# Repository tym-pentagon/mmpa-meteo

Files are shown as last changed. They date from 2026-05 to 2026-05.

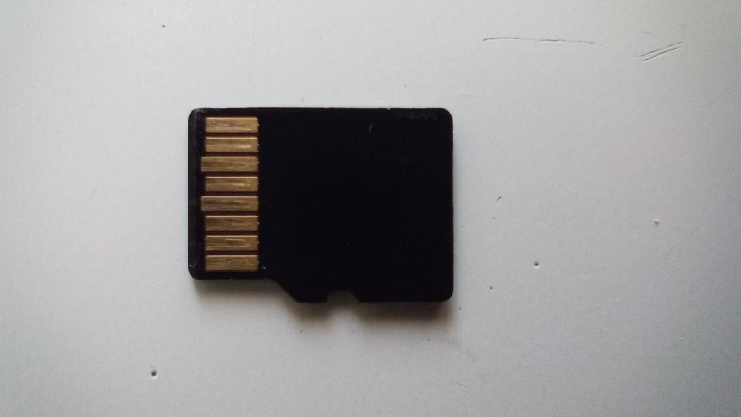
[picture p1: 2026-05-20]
Kod/Pomocne-skripty/obrazky/zdrojove-obrazky/sd_karta/sd_karta_fotka.jpeg

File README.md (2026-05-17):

# MMPa meteo
**MMPa meteo** je víceúčelová meteostanice určená pro analýzu atmosféry, magnetického pole Země a dalších jevů. 
Jedná se o projekt [týmu Pentagon](https://github.com/tym-pentagon). 

> [!TIP]
> Přečtěte si naši [dokumentaci](/Informace/README.md)!

> [!NOTE]
> #### Zdroje
> - [Knihovna pro ovládání ILI9486 LCD](https://github.com/RobertoBenjami/stm32_graphics_display_drivers)
> - [Knihovna pro ovládání SSD1306 OLED](https://github.com/afiskon/stm32-ssd1306)
> - [Čtení dat z BME280 přes I²C](https://controllerstech.com/interface-bme280-with-stm32/) - tutoriál
> - [BME280 datasheet](https://www.bosch-sensortec.com/media/boschsensortec/downloads/datasheets/bst-bme280-ds002.pdf)
> - [LoRa datasheet](https://www.mouser.com/pdfDocs/DS_LLCC68_V10-2.pdf)
> - [STM32 SD Card Interface via SPI and FatFS Tutorial (No RTOS)](https://www.youtube.com/watch?v=PBIm8BCnbyQ) - video tutoriál
> - Dimitar Toshkov Zhekov - Terminus Font
> - [Deepseek](https://chat.deepseek.com/) - generování programu pro export fontů
> - [ChatGPT](https://chatgpt.com/) & [GitHub Copilot modely](https://github.com/copilot) (studentská licence) - debugování

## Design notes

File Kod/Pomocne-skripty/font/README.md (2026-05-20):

# Font
Tato složka obsahuje skripty pro **vytváření a použití českého bitmapového fontu** v STM32CubeIDE. 

## [bdf-converter.py](./bdf-converter.py)
Konvertuje libovolný font ve formátu `.bdf` na soubor `.c`, který lze použít v STM32CubeIDE. 

### Použití
```bash
python3 bdf-converter.py input.bdf [output.c] [font_name]
```

### Zdroje
 - [DeepSeek](https://chat.deepseek.com/) - Generování kódu
 - Chyby v kódu opraveny týmem Pentagon

# Použití diakritiky
Vzhledem k tomu, že **STM32CubeIDE nepodporuje enkódování ISO-8859-2**, je pro zobrazení diakritiky a speciálních znaků potřeba text **převést do hexadecimálního formátu**. To obstarává skript [text-to-array.py](./text-to-array.py) (viz níže). 

## [text-to-array.py](./text-to-array.py)
Konvertuje **text na C array** s hexadecimálními hodnotami představujícími znaky ve formátu ISO-8859-2. 

### Použití
```bash
python3 text-to-array.py "your text here" [array_name]
```

### Zdroje
 - [DeepSeek](https://chat.deepseek.com/) - Generování kódu

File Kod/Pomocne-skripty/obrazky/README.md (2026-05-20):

# Obrázky
Tato složka obsahuje skripty pro **konvertování PNG obrázků na C skripty pro použití** v STM32CubeIDE. 

## [png-converter.py](./png-converter.py)
Konvertuje libovolný obrázek ve formátu `.png` na soubor `.c`, který lze použít v STM32CubeIDE. 

### Použití
```bash
python3 png-converter.py input.png image_name output.c
```

### Zdroje
 - [DeepSeek](https://chat.deepseek.com/) - Generování kódu
 - Kód byl částečně upraven týmem Pentagon

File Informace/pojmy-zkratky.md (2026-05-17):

## Pojmy a zkratky
Dokumentace k `MMPa meteo` využívá několik technických pojmů, které je třeba znát. Následující obsah je sestaven pro nováčky, kteří se projektu snaží porozumět.

| Zkratka | Pojem | Překlad | Definice
|-|-|-|-
|ADC|Analog-Digital converter|Analogově-digitální převaděč|Převaděč napětí na logické signály.
|DAC|Digital-Analog converter|Digitálně-analogový převaděč|Zdroj napětí nastavitelný logickými signály.
|DMA|Direct Memory Access|Přímý přístup do paměti|Funkcionalita umožňující periferii psát přímo do paměti MCU.
|MCU|MicroController unit|Mikrokontrolérová jednotka, mikrokontrolér|Jednotka, na které běží kód, matematické operace apod.
| |Peripheral|Periferie|Rozšíření funkčnosti a možností MCU.
|TIM|Timer|Časovač|Periferie určená k počtu a odpočtu.

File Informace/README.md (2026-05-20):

> [!WARNING]
> Tato dokumentace zahrnuje obecný stav projektu, nikoliv jeho vnitřní tok. Namísto vysvětlování je pro tento účel dočasně postavena prezentace [Mikrokontroléry letí 2026](about:blank).

> [!IMPORTANT]
> ### Stanice `MMPa meteo` se momentálně skládá ze dvou desek.
> **Deska vnější** je vybavena sensory, ze kterých po intervalech čte data a technologií [LoRa](/Informace/README.md#komunikace) je posílá desce vnitřní.  
> **Deska vnitřní** data přijímá z desky vnější, ukazuje je uživateli a zapisuje do SD karty.

> [!TIP]
> Projekt je budován tak, aby naplnil [základní kompetenční ustanovení](Informace/zakladni-kompetecni-listina.md).  
> Projekt při operaci musí naplňovat stanovení **MVP** (**M**inimum **V**iable **P**roduct), označeno ⁕.

## Složení stanice
`[`Ozávorkované`]` body čekají na implementaci.  
```mermaid
ishikawa-beta
    MMPa assembly
    Senzory
        [Akustický anemometr]
          rychlost větru
        BME280
          teplota
          relativní vlhkost
          tlak
        [osvětlení]
        [akcelerace (zemětřesení)]
    Komunikace
        Wireless
          LoRa
          [Bluetooth]
          [2.4 GHz Wi-Fi]
          [5 GHz Wi-Fi]
        Wired
          [RS-422]
          [RS-485]
    User
        INPUT
            Rotační enkodér
        OUTPUT
            Displej
            SD karta
    +
      GPS
```
> [!TIP]
> Pokud jsi **nováček**, doporučujeme přečíst [Pojmy & zkratky](/Informace/pojmy-zkratky.md).
### Senzorová soustava
| Veličina || Senzor | Vstup | Výstup |
|:---:|:-:|:---:|:---:|:---:|
||||||
| Vítr - rychlost ||  Akustický anemometr dvouosý  | 2x zvuková křivka | $\text{ms}^{-1}$ | 
| Vítr - směr ||  Akustický anemometr dvouosý  | 2x zvuková křivka | $\degree$ |
| Teplota |⁕| BME280 | Binární data | $\textdegree C$ |
| Vlhkost |⁕| BME280 | Binární data | % |
| Tlak |⁕| BME280 | Binární data | $\text{MPa}$ |
| Čas |⁕| GPS | LoRa | $\text{ms}$ |
| Zemětřesení ||  Akcelerometr LIS3DH  | *TBD* |  st. zemětřesení  |
| Světlo || 2 diody BPW34S | Analog. | oblačnost |
#### BME280
BME je modul měříci teplotu, vlhkost vzduchu a tlak okolí. K desce je připojen přes **SPI**.
##### Pocitová teplota
K teplotě ještě řadíme **pocitovou teplotu**, kterou získáme ze vzorce, přičemž potřebujeme hodnotu:
 - reálné teploty
 - rychlosti větru
 - vlhkosti vzduchu

Možné vzorce pro použití:
- [AAT](https://en.wikipedia.org/wiki/Apparent_temperature)  (australský systém, navržen pro celoroční výpočty)
- [Wind Chill](https://en.wikipedia.org/wiki/Wind_chill)  (kanadský standard, navržen pro nižší teploty cca do 10°C)
- [Heat Index](https://en.wikipedia.org/wiki/Heat_index) (pro teplejší počasí nad 27°C s vlhkostí nad 40%)

>[!NOTE]
>Vzorce jsou hlavně určené pro měření ve **stínu**.  
>Lze použít více vzorců pro různá období.  
  
#### Osvětlení
Pro detekci osvětlení se používají dvě fotodiody [BPW34S](https://look.ams-osram.com/m/1f206a499ac1f0b2/original/BPW-34-S.pdf). Jejich výstupy budou zavedeny do MCU jako kanály nízkofrekvenčního ADC
Každá fotodioda je sériově připojena k resistoru s odporem $R$ a k němu paralelně operačnímu zesilovači.
- **Denní osvětlení** vrací dioda `D800`, na kterou navazuje se zesilovačem odpor $R = 10 \text{ k}\Omega$, dokážeme s ní tedy zachycovat makroskopické měřítko s přesností pro denní svit dostatečnou.
- **Noční osvětlení** (světelný smog) vrací dioda `D801`, kde $R = 1 \text{ M}\Omega$, lze s ní receptovat malé rozmezí s velmi velkou přesností.
Spoluprácí obou diod dokážeme optimálně pokrýt celé reálné světelné rozmezí.

Viz. [schéma](/Schema/schema.pdf).

### Komunikace

| Typ komunikace || Rychlost | Dosah  |
|---|-|---|---|
| [LoRa](https://cs.wikipedia.org/wiki/LoRa)|⁕| 11 $\text{bps}$ - 203 $\text{kbps}$ | 4.8 $\text{km}$ |
| 2.4 $\text{GHz}$ Wi-Fi  || 450 $\text{Mbps}$ - 600 $\text{Mbps}$ | 36 $\text{m}$ |
| 5 $\text{GHz}$ Wi-Fi || 1.3 $\text{Gbps}$ | 12 $\text{m}$ |
| [Bluetooth](https://cs.wikipedia.org/wiki/Bluetooth)|| dle verze (max 24 $\text{MBps}$)| dle verze (max 100 $\text{m}$)|
> [!NOTE]
> Jde pouze o přibližné hodnoty, skutečný dosah a rychlost budou omezeny rychlostí mikrokontroléru, rušením signálu a typem prostředí. 

#### LoRa: Předávané proměnné
| Index | Typ proměnné |  Název proměnné  |
|---|---|---|
| 0-1 | int16_t | cas.rok |
| 2 | int8_t | cas.mesic |
| 3 | int8_t | cas.den |
| 4 | int8_t | cas.hodiny |
| 5 | int8_t | cas.minuty |
| 6 | int8_t | cas.sekundy |
| 7-10	| int32_t | teplota |
| 11-14	| uint32_t | vlhkost |
| 15-18 | uint32_t | tlak |
| 19-60 | | |
| 61 | uint8_t | crc |

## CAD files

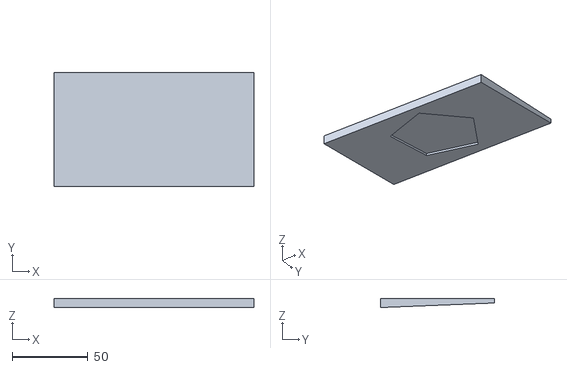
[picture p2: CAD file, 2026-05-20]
Modely/Monitor unit roof.stl
132.0 x 75.0 x 6.00

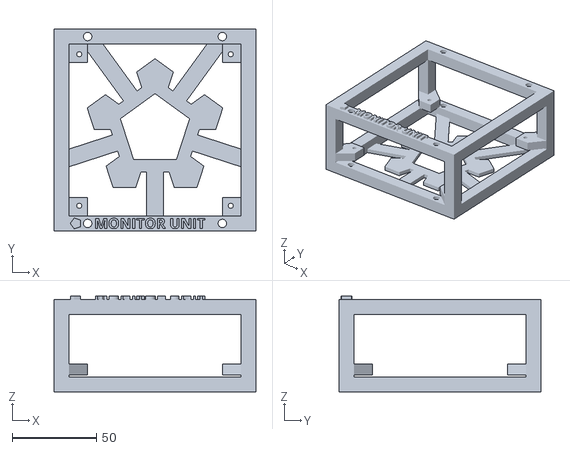
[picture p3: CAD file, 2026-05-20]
Modely/Monitor unit PCB holder.stl
120.0 x 120.0 x 57.0

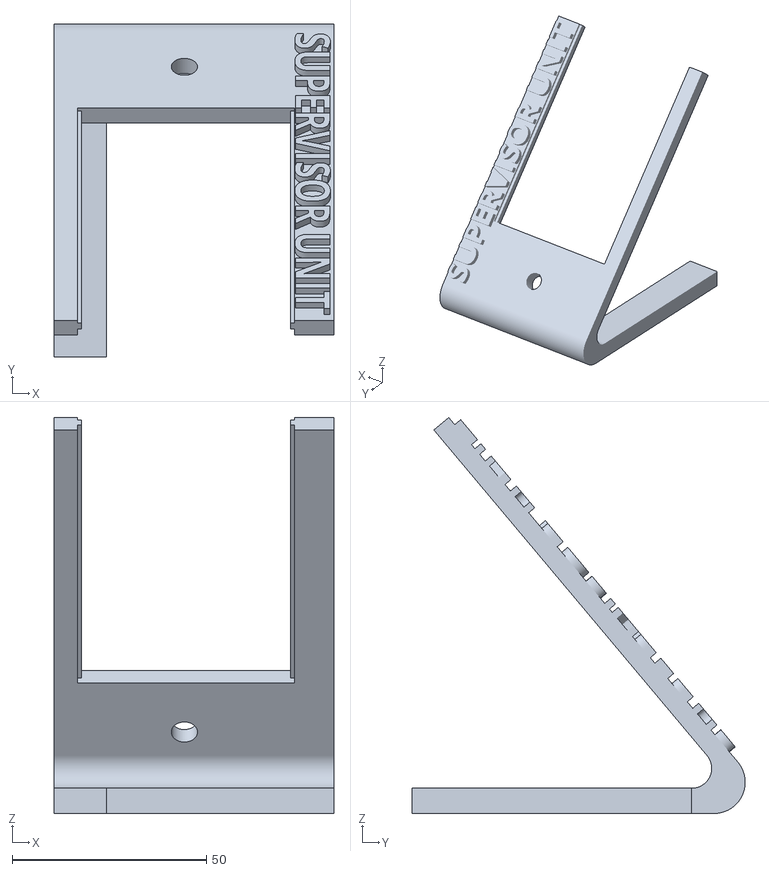
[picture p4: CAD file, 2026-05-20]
Modely/Supervisor unit display holder.stl
72.0 x 85.8 x 101.9

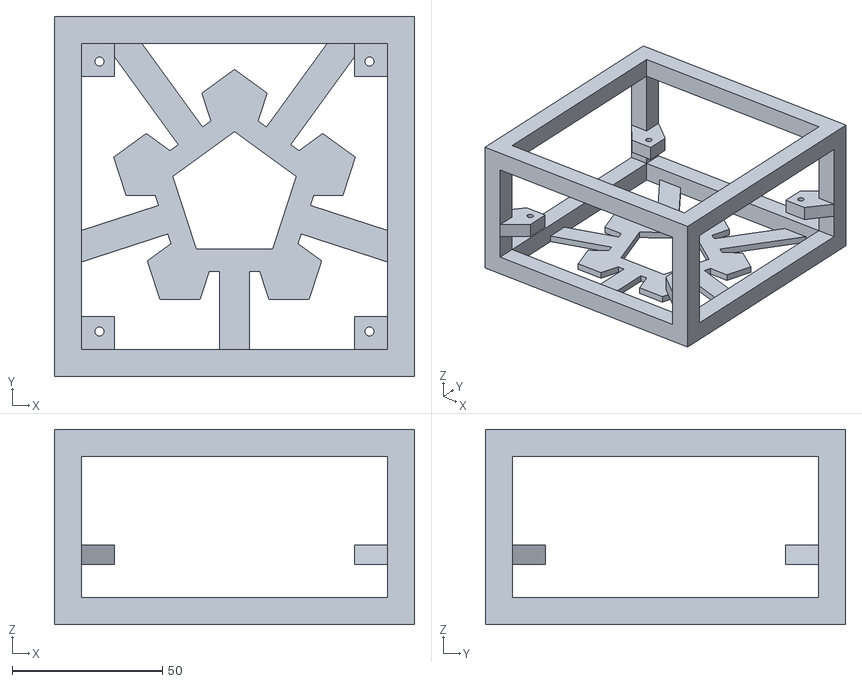
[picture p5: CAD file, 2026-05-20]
Modely/Supervisor unit PCB holder.stl
120.0 x 120.0 x 65.0

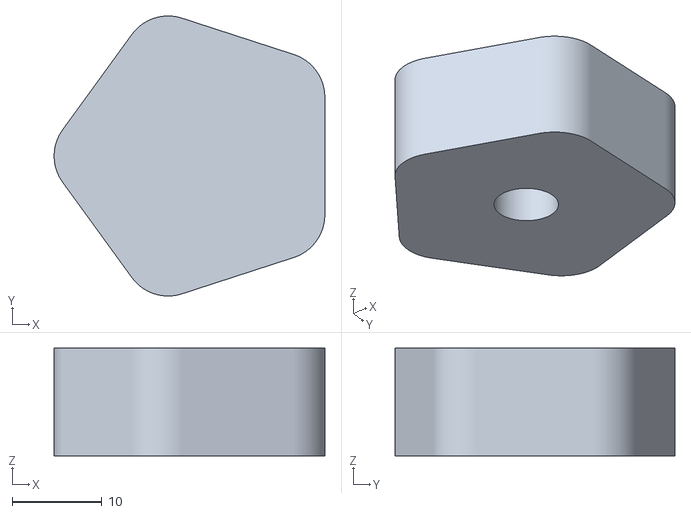
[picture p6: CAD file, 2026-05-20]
Modely/Supervisor unit rotary encoder knob.stl
30.1 x 31.2 x 12.0

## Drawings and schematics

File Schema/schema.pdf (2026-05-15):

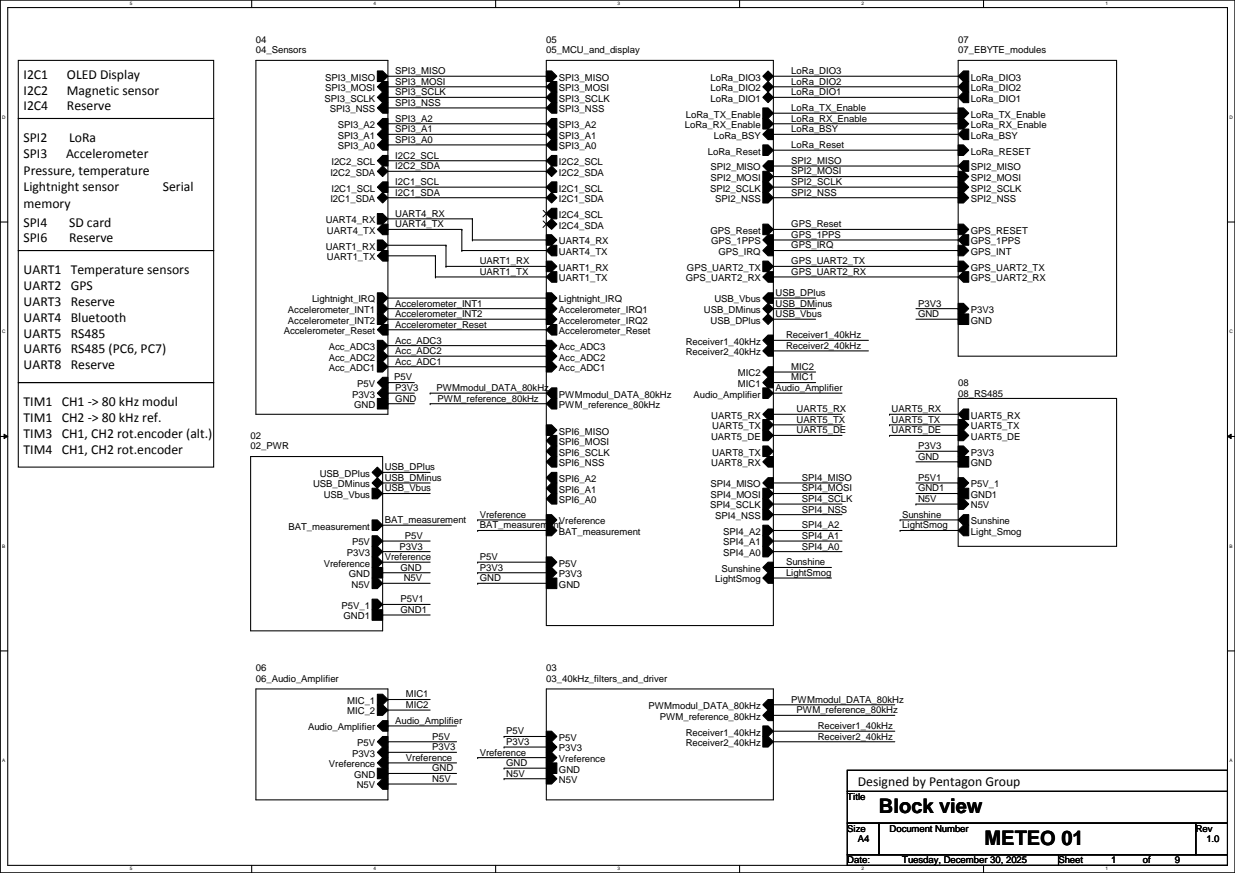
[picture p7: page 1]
Vreference; GND; GND N5V; Audio_Amplifier; GND1; USB_Vbus; USB_DPlus USB_DMinus; P3V3 GND; MIC2; MIC1; USB_DMinus; USB_DPlus; PWMmodul_DATA_80kHz PWM_reference_80kHz; UART5_RX UART5_TX UART5_DE; LoRa_DIO3; LoRa_RX_Enable; SPI2_MISO SPI2_MOSI SPI2_SCLK; GPS_1PPS; GPS_UART2_RX; GPS_IRQ GPS_UART2_TX; Receiver1_40kHz Receiver2_40kHz; SPI3_MISO; SPI3_A2; I2C2_SCL I2C2_SDA I2C1_SCL; UART4_TX; UART1_RX UART1_TX; Accelerometer_INT1 Accelerometer_INT2 Accelerometer_Reset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

SPI3_MOSI | LoRa_DIO2
SPI3_SCLK | LoRa_DIO1
SPI3_NSS | LoRa_TX_Enable

SPI3_A1 | LoRa_BSY
SPI3_A0 | LoRa_Reset

I2C1_SDA | SPI2_NSS

UART4_RX | GPS_Reset

TIM1 CH1 -> 80 kHz modul
TIM1 CH2 -> 80 kHz ref.
TIM3 CH1, CH2 rot.encoder (alt.)
TIM4 CH1, CH2 rot.encoder

Designed by Pentagon Group
Title
Block view

## Power Supply ±5 V

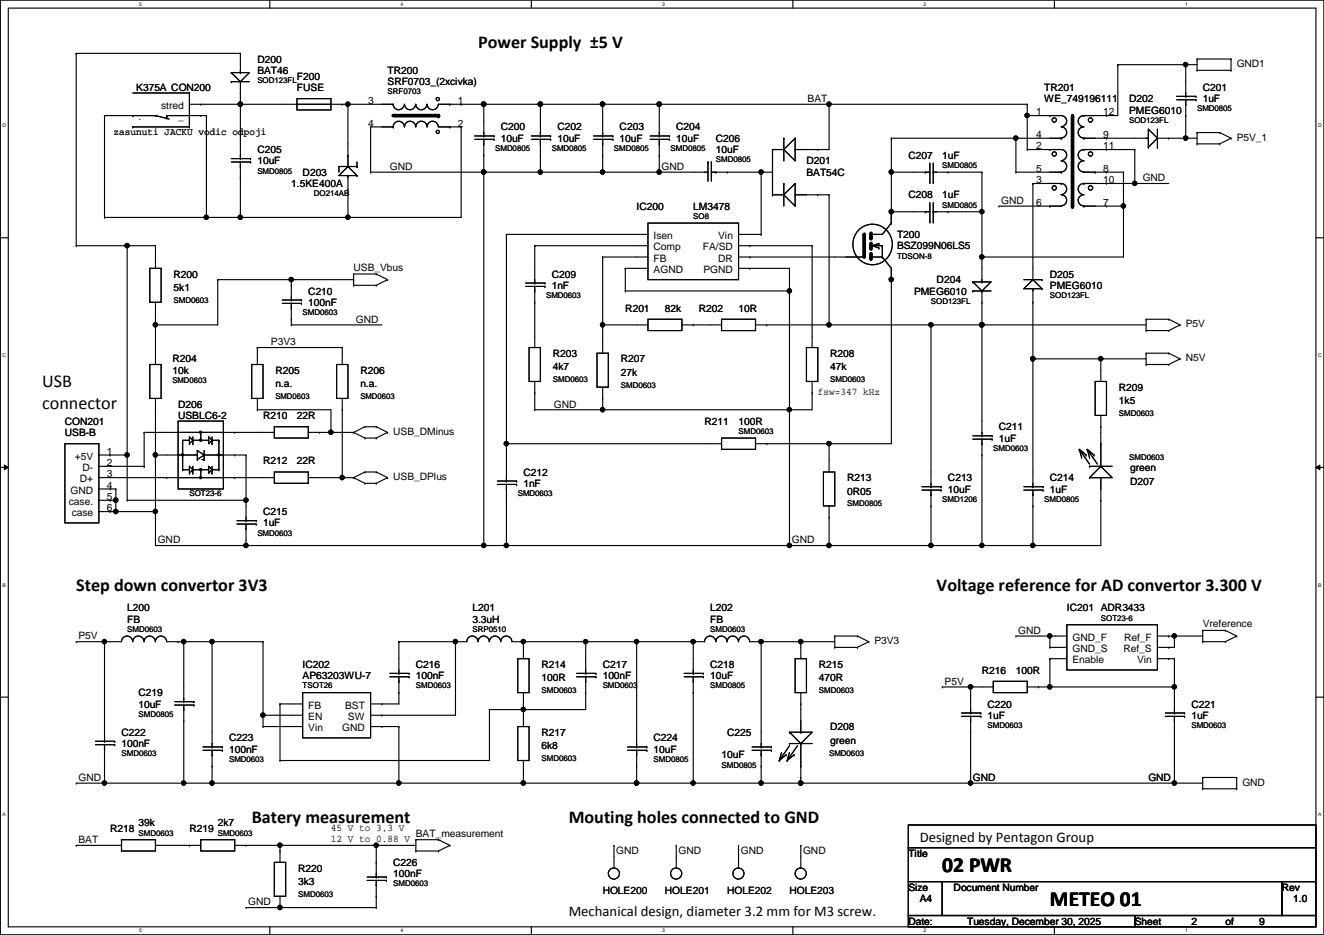
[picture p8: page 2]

zasunuti JACKU vodic odpoji

Mouting holes connected to GND

Designed by Pentagon Group
Title
02 PWR

HOLE200
Mechanical design, diameter 3.2 mm for M3 screw.

## Ultrasound receiver 1 filter (40 kHz)

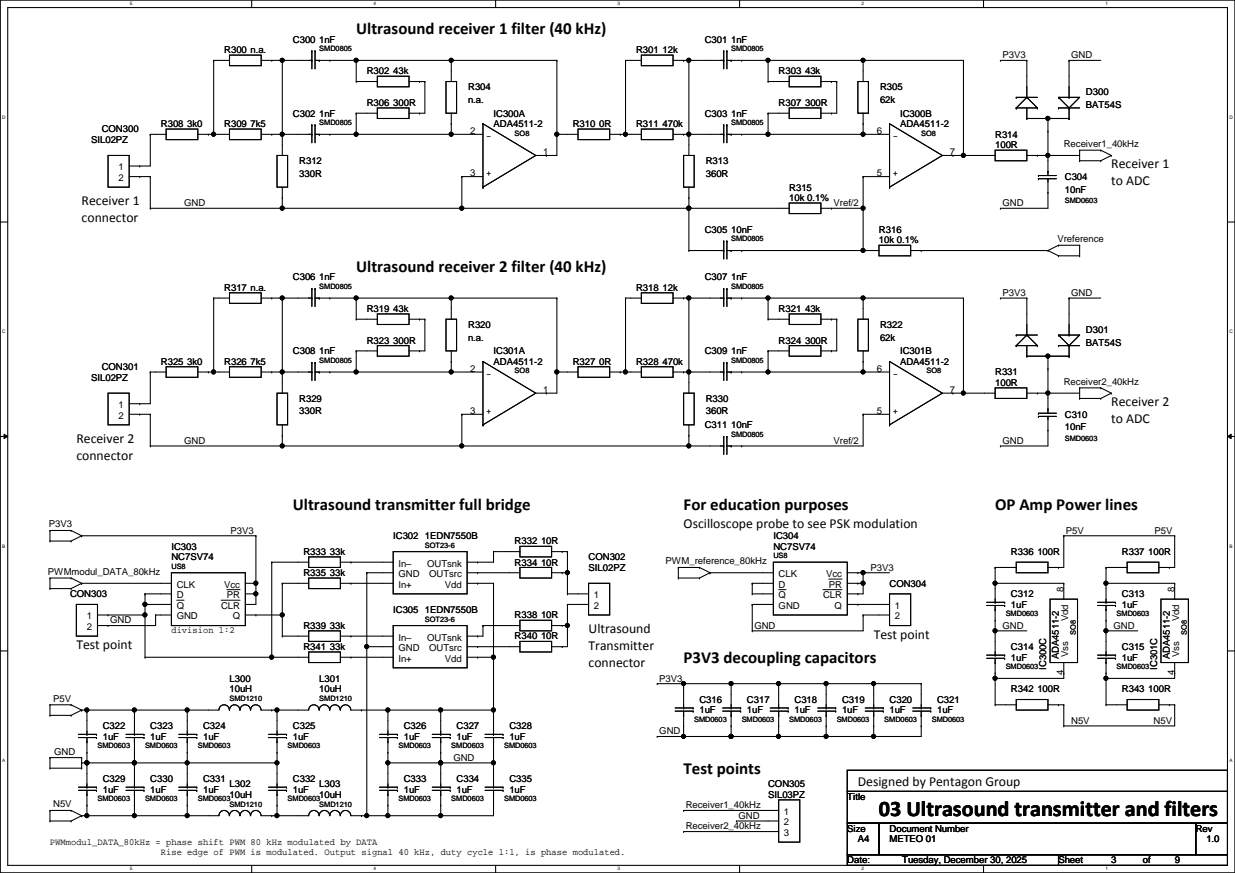
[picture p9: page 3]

Ultrasound receiver 2 filter (40 kHz)

For education purposes
Oscilloscope probe to see PSK modulation

Designed by Pentagon Group
Title
03 Ultrasound transmitter and filters

PWMmodul_DATA_80kHz = phase shift PWM 80 kHz modulated by DATA

Rise edge of PWM is modulated. Output signal 40 kHz, duty cycle 1:1, is phase modulated.

## Bluetooth

## Accelerometer

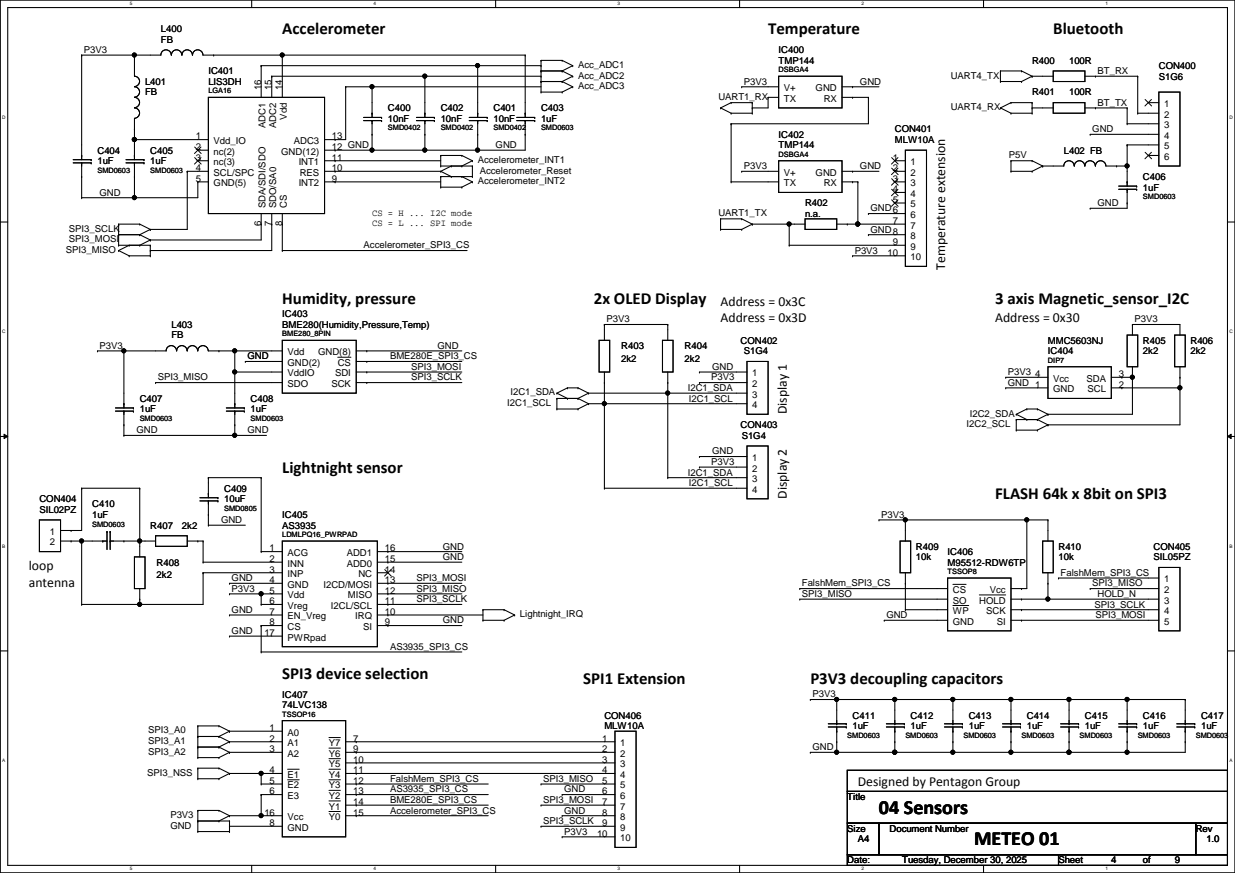
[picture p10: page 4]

9 IRQ 10 I2CL/SCL 11 MISO 12 I2CD/MOSI 13 NC 14 ADD0 15 ADD1 16

P3V3 decoupling capacitors SPI3 device selection

## SWD connector

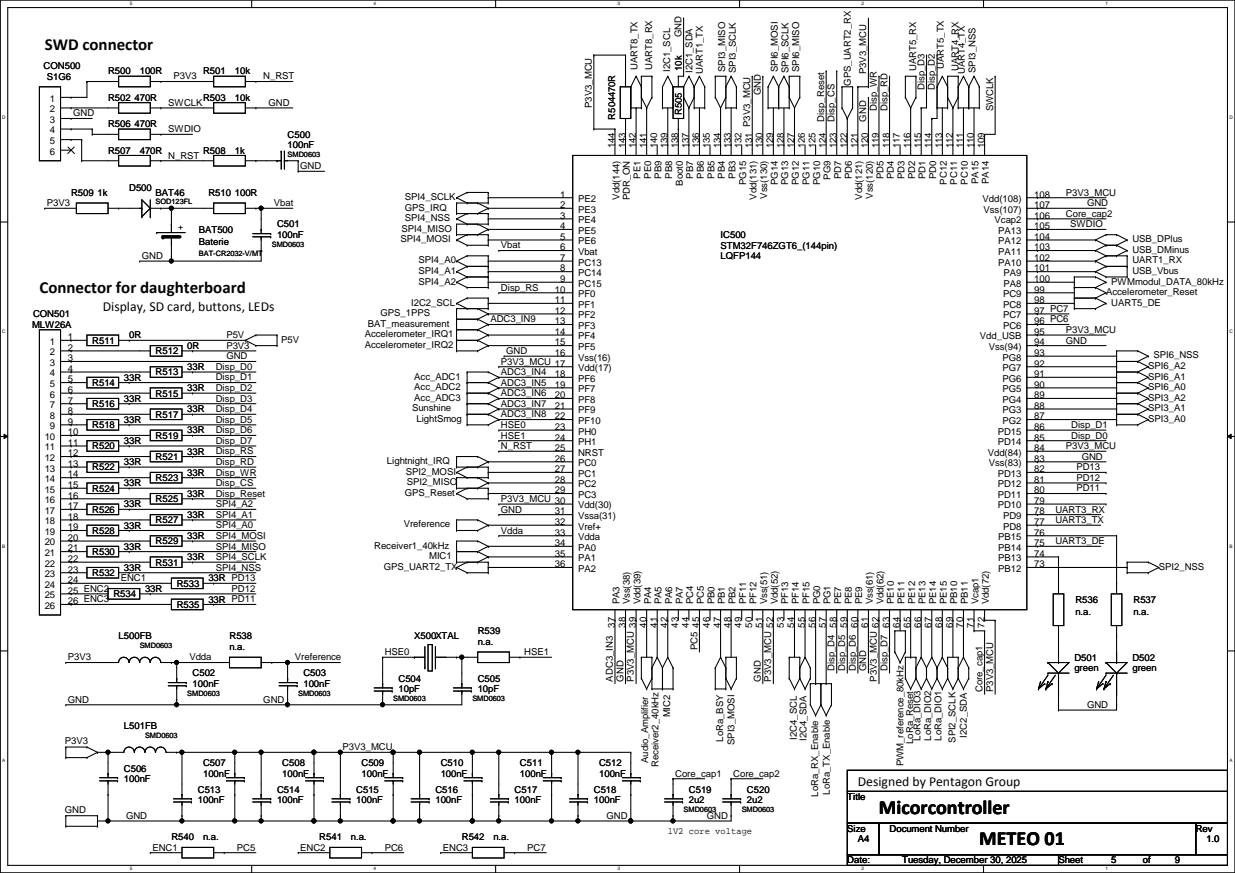
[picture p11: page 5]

Display, SD card, buttons, LEDs

Designed by Pentagon Group
Title
Micorcontroller

L600 FB | Audio Amplifier

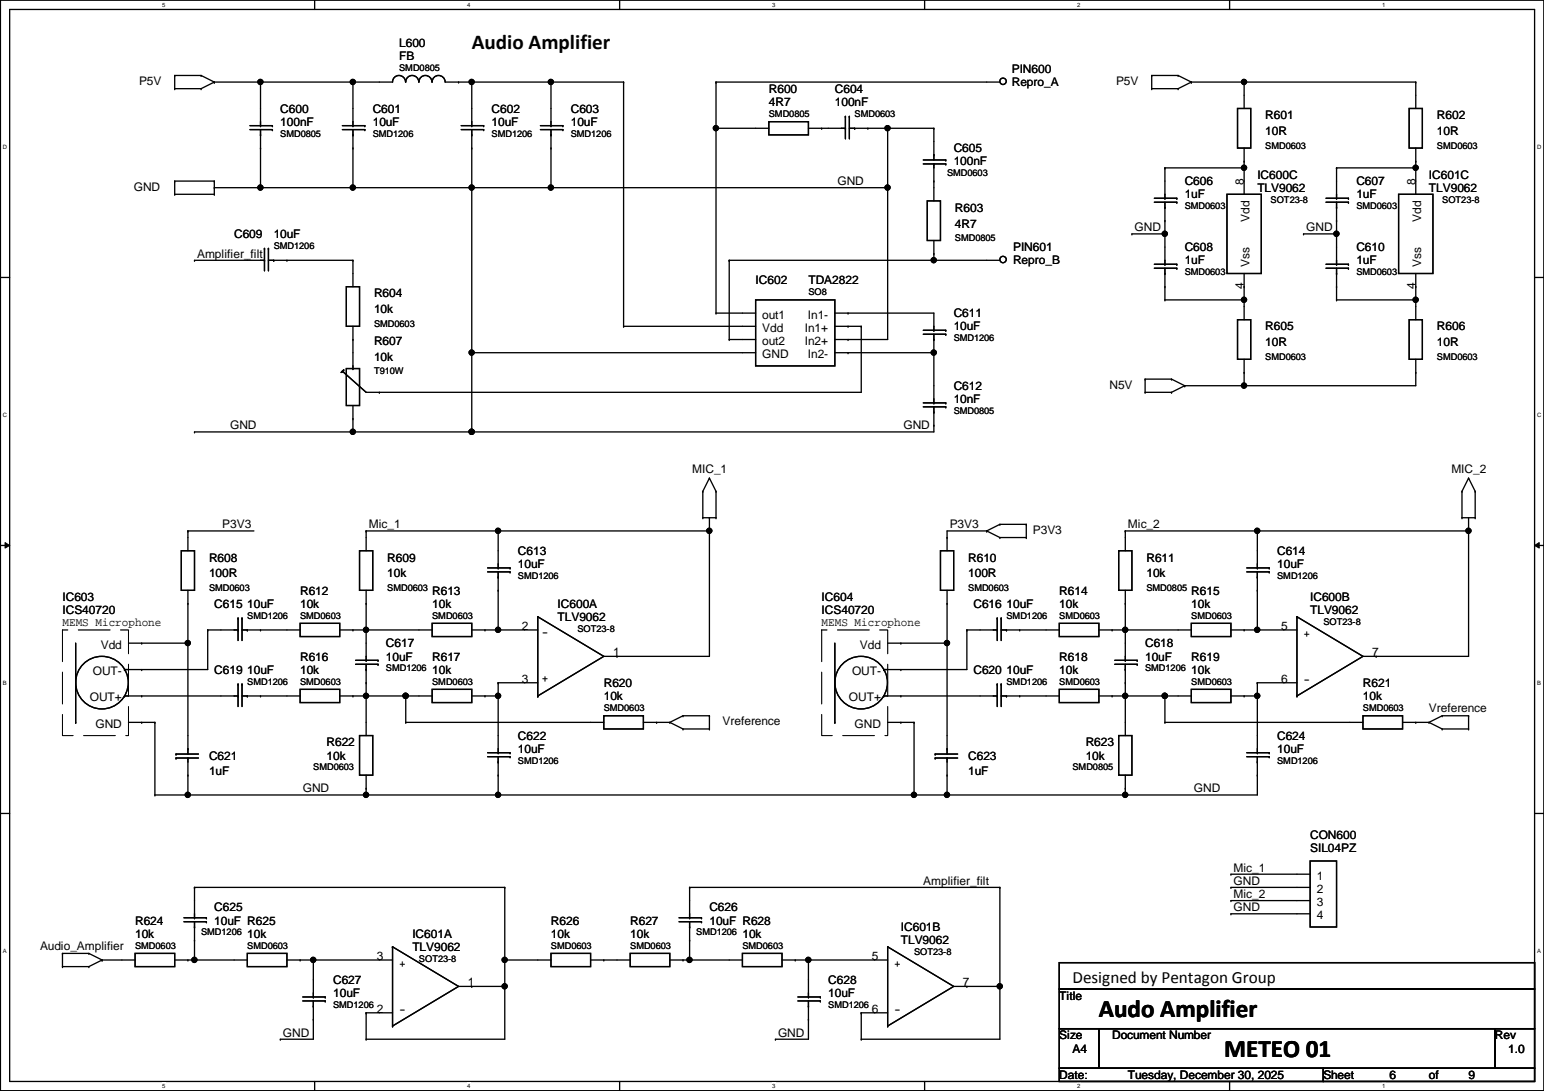
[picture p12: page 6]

SMD0805 | SMD0603

Designed by Pentagon Group
Title
Audo Amplifier

## GPS

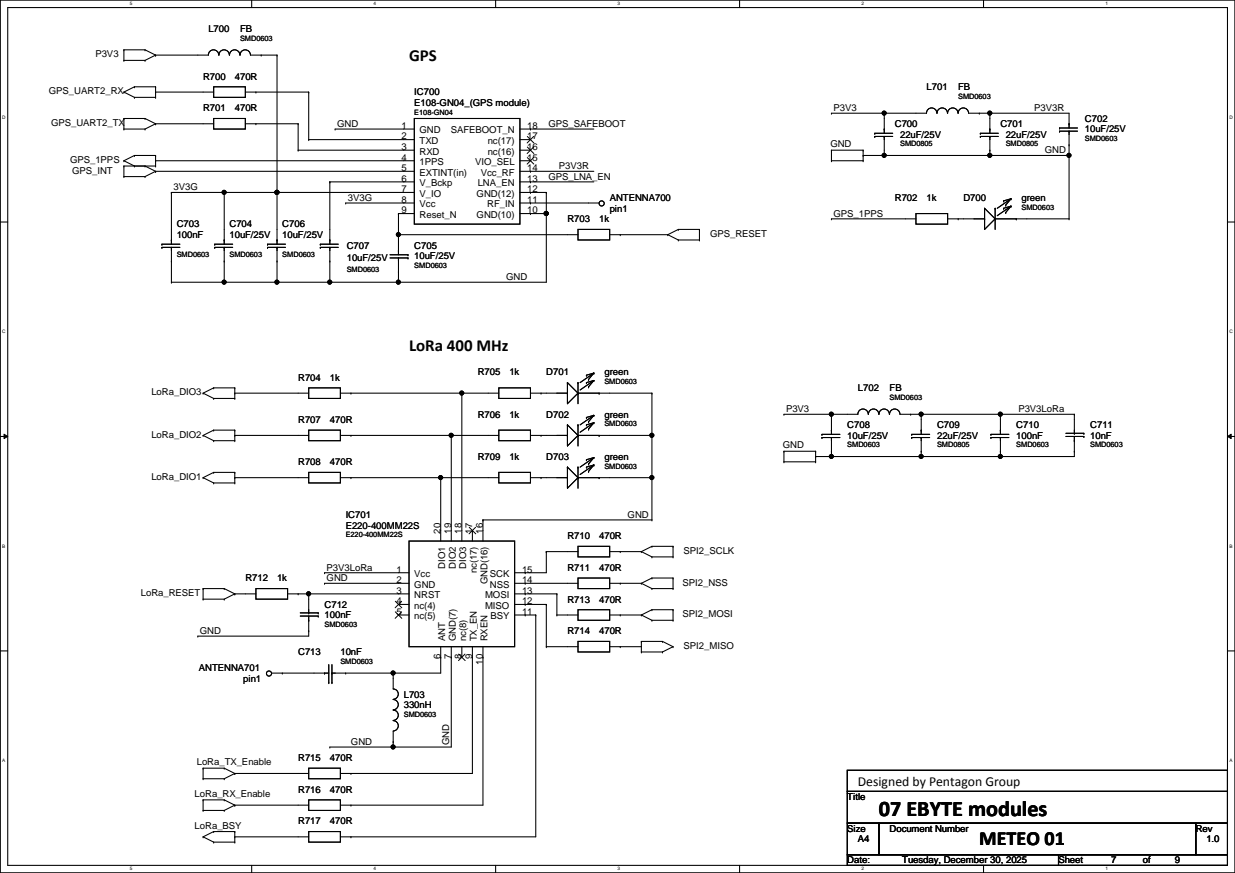
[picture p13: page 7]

DIO3
BSY 11 MISO 12 MOSI 13 NSS 14 SCK 15

Designed by Pentagon Group
Title
07 EBYTE modules

## RS485 Interface

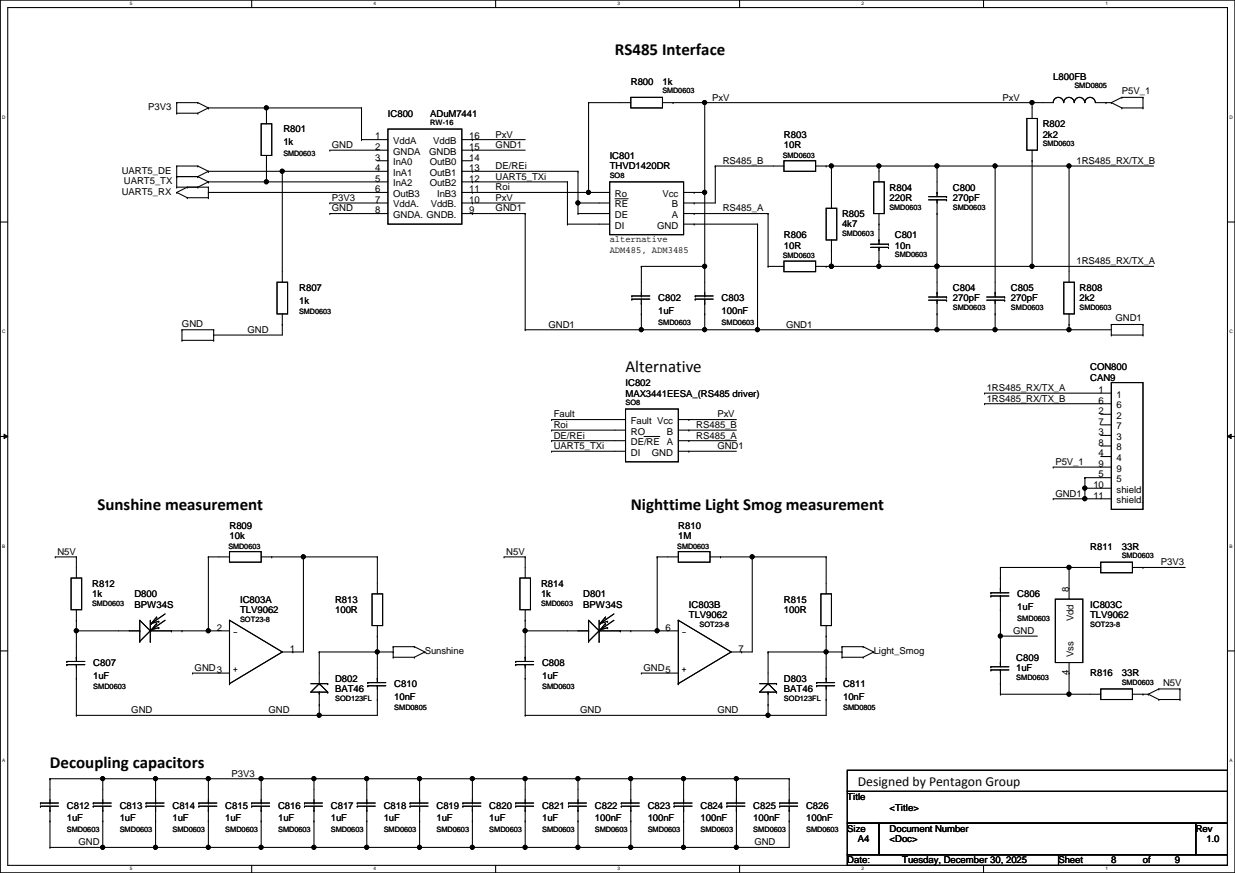
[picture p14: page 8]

Designed by Pentagon Group
Title

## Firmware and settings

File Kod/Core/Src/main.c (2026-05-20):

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
/* Includes ------------------------------------------------------------------*/
#include "main.h"
#include "adc.h"
#include "fatfs.h"
#include "i2c.h"
#include "spi.h"
#include "tim.h"
#include "usart.h"
#include "gpio.h"

/* USER CODE BEGIN Includes */
#include "stm32_adafruit_lcd.h"
#include "ssd1306.h"
#include "stdio.h"
#include "string.h"
#include "stdarg.h" // For va_list var arg functions
#include "stdbool.h"
#include "sd.h"

/* Komunikace */
#include "lora.h"

/* Senzory */
#include "bme280.h"
#include "gps.h"

/* Stránky */
#include "hlavni_menu.h"
#include "atmosfera.h"
/* USER CODE END Includes */


/* USER CODE BEGIN PV */
bool pripojeno = 1;
uint16_t ping = 9999;

Cas predchozi_cas = {2026, 4, 15, 14, 39, 2}; // Čas při předchozí aktualizace hodin
extern Cas cas;

uint16_t predchozi_pozice_vyberu = 0;
uint16_t pozice_vyberu = 0;
uint16_t max_pozice_vyberu = 10;

int32_t teplota;
uint32_t vlhkost, tlak;

int32_t teplota_venku;
uint32_t vlhkost_venku, tlak_venku;

bool stisknuto = 0; // Zda bylo stisknuto tlačítko na rotačním enkodéru

extern bool sd_karta_pripojena;
extern uint32_t kapacita_sd_karty;
extern uint32_t zaplneni_sd_karty;

uint8_t strana = 0;

const char nazvy_mesicu[12][10] = {
	{0x6C, 0x65, 0x64, 0x6E, 0x61, 0x00},							// "ledna"
	{0xFA, 0x6E, 0x6F, 0x72, 0x61, 0x00},							// "února"
	{0x62, 0xF8, 0x65, 0x7A, 0x6E, 0x61, 0x00},						// "března"
	{0x64, 0x75, 0x62, 0x6E, 0x61, 0x00},							// "dubna"
	{0x6B, 0x76, 0xEC, 0x74, 0x6E, 0x61, 0x00},						// "května"
	{0xE8, 0x65, 0x72, 0x76, 0x6E, 0x61, 0x00},						// "června"
	{0xE8, 0x65, 0x72, 0x76, 0x65, 0x6E, 0x63, 0x65, 0x00},			// "července"
	{0x73, 0x72, 0x70, 0x6E, 0x61, 0x00},							// "srpna"
	{0x7A, 0xE1, 0xF8, 0xED, 0x00},									// "září"
	{0xF8, 0xED, 0x6A, 0x6E, 0x61, 0x00},							// "října"
	{0x6C, 0x69, 0x73, 0x74, 0x6F, 0x70, 0x61, 0x64, 0x75, 0x00},	// "listopadu"
	{0x70, 0x72, 0x6F, 0x73, 0x69, 0x6E, 0x63, 0x65, 0x00}			// "prosince"
};
/*
 * 0 - hlavní menu
 */

char debug[500];

extern bool can_send_data; // Zda LoRa může posílat data

uint8_t lora_data[DATA_LEN]; // Data pro odeslání

extern bool jednotka_ma_gps;
extern bool jednotka_ziskala_cas_z_gps;

bool mereni = false; // Zda se MCU má ptát senzorů na aktuální hodnoty
bool je_cas_zapsat_log = false;
// Měří se každou sekundu
// Omezení je z důvodu přehřívání senzorů
/* USER CODE END PV */

void SystemClock_Config(void);
static void MPU_Config(void);
/* USER CODE BEGIN PFP */
void aktualizujCas(Cas *cas);
void aktualizujPoziciVyberu(void);
void tlacitkoStisknuto(void);
void pridatChecksum(uint8_t data[], size_t data_len);
void pripravitDataProOdeslani(void);
bool zkontrolovatChecksum(uint8_t data[], size_t data_len);
/* USER CODE END PFP */

/* USER CODE BEGIN 0 */
void aktualizujCas(Cas *cas) {
	/* Tato funkce se spustí každou sekundu, vždy aktualizuje proměnnou cas */
	cas->sekundy ++;

	if (cas->sekundy >= 60) {
		cas->sekundy = 0;
		cas->minuty ++;

		if (cas->minuty >= 60) {
			cas->minuty = 0;
			cas->hodiny ++;

			if (cas->hodiny >= 24) {
				cas->hodiny = 0;
				cas->den ++;

				if (
					(cas->den >= 31 && (		// Měsíce se 31 dny
						cas->mesic == 1 ||		// Leden
						cas->mesic == 3 ||		// Březen
						cas->mesic == 5 || 		// Květen
						cas->mesic == 7 ||		// Červenec
						cas->mesic == 8 ||		// Srpen
						cas->mesic == 10 ||		// Říjen
						cas->mesic == 12		// Prosinec
					)) ||
					(cas->den > 30 && (			// Měsíce se 30 dny
						cas->mesic == 4 ||		// Duben
						cas->mesic == 6 ||		// Červen
						cas->mesic == 9 || 		// Září
						cas->mesic == 11		// Listopad
					)) ||
					(cas->den >= 29 && cas->rok % 4 == 0 && cas->rok % 100 != 0 && cas->rok % 400 == 0) ||	// Únor v přestupném roku
					cas->den >= 28																			// Únor v nepřestupném roku
				) {
					cas->den = 0;
					cas->mesic ++;

					if (cas->mesic >= 13) {
						cas->mesic = 1;
						cas->rok ++;
					}
				}
			}
		}
	}
}

void aktualizujPoziciVyberu(void) {
	if (TIM3->CNT % 2 == 0 && TIM3->CNT != pozice_vyberu * 2) {
		predchozi_pozice_vyberu = pozice_vyberu;

		if (TIM3->CNT > 65000) { // Underflow
			TIM3->CNT = (max_pozice_vyberu + 1) * 2 - ((65536 - TIM3->CNT) % ((max_pozice_vyberu + 1) * 2));
		}

		if (TIM3->CNT > max_pozice_vyberu * 2) {
			TIM3->CNT = TIM3->CNT % ((max_pozice_vyberu + 1) * 2);
		}

		pozice_vyberu = TIM3->CNT / 2;

		if (strana == 0) {
			aktualizujPoziciVyberuVHlavnimMenu(predchozi_pozice_vyberu, pozice_vyberu);
		}

		/* Vypíše na debug displej */
		char pozice_vyberu_buffer[6];
		snprintf(pozice_vyberu_buffer, 6, "%d", pozice_vyberu);

		ssd1306_SetCursor(122, 0);
		ssd1306_WriteString(pozice_vyberu_buffer, &Terminus12Bold, 1);
		ssd1306_UpdateScreen();
	}
}

void tlacitkoStisknuto(void) {
	ssd1306_SetCursor(122, 13);
	ssd1306_WriteString("1", &Terminus12Bold, 1);
	ssd1306_UpdateScreen(); // Vykreslí na OLED displej

	if (strana == 0) {
		if (pozice_vyberu == 0) {
			strana = 1;
			vykresliStrankuAtmosfera(&predchozi_pozice_vyberu, &pozice_vyberu, &max_pozice_vyberu);
		}
	}
	else if (strana == 1) {
		if (pozice_vyberu == 0) {
			strana = 0;
			vykresliHlavniMenu(pripojeno, ping, cas, &predchozi_pozice_vyberu, &pozice_vyberu, &max_pozice_vyberu);
		}
	}

	ssd1306_SetCursor(122, 13);
	ssd1306_WriteString("0", &Terminus12Bold, 1);
	ssd1306_UpdateScreen(); // Vykreslí na OLED displej
}

void pridatChecksum(uint8_t data[], size_t data_len) {
	uint8_t crc = 0;

	for (size_t i = 0; i < data_len - 1; i ++) {
		crc ^= data[i];
	}

	data[data_len - 1] = crc;
}

void pripravitDataProOdeslani() {
	memset(lora_data, 0, DATA_LEN); // Vynuluje data pro odeslání

	if (jednotka_ziskala_cas_z_gps) {
		lora_data[0] = (cas.rok >> 8) & 0xFF; // MSB
		lora_data[1] = cas.rok & 0xFF; // LSB

		lora_data[2] = cas.mesic;
		lora_data[3] = cas.den;

		lora_data[4] = cas.hodiny;
		lora_data[5] = cas.minuty;
		lora_data[6] = cas.sekundy;
	}

	lora_data[7] = (teplota >> 24) & 0xFF; // MSB
	lora_data[8]  = (teplota >> 16) & 0xFF;
	lora_data[9] = (teplota >> 8)  & 0xFF;
	lora_data[10] = teplota & 0xFF;         // LSB

	lora_data[11] = (vlhkost >> 24) & 0xFF; // MSB
	lora_data[12]  = (vlhkost >> 16) & 0xFF;
	lora_data[13] = (vlhkost >> 8)  & 0xFF;
	lora_data[14] = vlhkost & 0xFF;         // LSB

	lora_data[15] = (tlak >> 24) & 0xFF; // MSB
	lora_data[16]  = (tlak >> 16) & 0xFF;
	lora_data[17] = (tlak >> 8)  & 0xFF;
	lora_data[18] = tlak & 0xFF;         // LSB

	pridatChecksum(lora_data, DATA_LEN);

	LoRa_set_data(lora_data, sizeof(lora_data));
}

bool zkontrolovatChecksum(uint8_t data[], size_t data_len) {
	uint8_t crc = 0;

	for (size_t i = 0; i < data_len - 1; i ++) {
		crc ^= data[i];
	}

	if (data[data_len - 1] == crc) {
		return true; // Checksum sedí
	}
	else {
		return false; // Checksum nesedí
	}
}

void LoRa_Rx_callback(uint8_t data_received[], uint8_t len) {
	if (!zkontrolovatChecksum(data_received, len)) {
		// Checksum nesedí
		// TODO: Error handling
	}

	if (!jednotka_ma_gps && (data_received[0] != 0 || data_received[1] != 0 || data_received[2] != 0 || data_received[3] != 0 || data_received[4] != 0 || data_received[5] != 0 || data_received[6] != 0)) {
		cas.rok =
			((uint16_t)data_received[0] << 8) |
			((uint16_t)data_received[1]);

		cas.mesic = (uint8_t)data_received[2];
		cas.den = (uint8_t)data_received[3];

		cas.hodiny = (uint8_t)data_received[4];
		cas.minuty = (uint8_t)data_received[5];
		cas.sekundy = (uint8_t)data_received[6];
	}

	teplota_venku =
		(int32_t)(
			((uint32_t)data_received[7] << 24) |
			((uint32_t)data_received[8] << 16) |
			((uint32_t)data_received[9] << 8)  |
			((uint32_t)data_received[10])
		);

	vlhkost_venku =
		((uint32_t)data_received[11] << 24) |
		((uint32_t)data_received[12] << 16) |
		((uint32_t)data_received[13] << 8)  |
		((uint32_t)data_received[14]);

	tlak_venku =
		((uint32_t)data_received[15] << 24) |
		((uint32_t)data_received[16] << 16) |
		((uint32_t)data_received[17] << 8)  |
		((uint32_t)data_received[18]);
}
/* USER CODE END 0 */

/**
  * @brief  The application entry point.
  * @retval int
  */
int main(void)
{

  /* MPU Configuration--------------------------------------------------------*/
  MPU_Config();

  /* MCU Configuration--------------------------------------------------------*/

  /* Reset of all peripherals, Initializes the Flash interface and the Systick. */
  HAL_Init();

  /* USER CODE BEGIN Init */
  HAL_Delay(2000); // Počká, než se všechny periferie inicializují a jsou schopné komunikovat.
  /* USER CODE END Init */

  /* Configure the system clock */
  SystemClock_Config();

  /* Initialize all configured peripherals */
  MX_GPIO_Init();
  MX_ADC3_Init();
  MX_TIM3_Init();
  MX_I2C1_Init();
  MX_SPI4_Init();
  MX_FATFS_Init();
  MX_TIM13_Init();
  MX_TIM2_Init();
  MX_SPI3_Init();
  MX_SPI2_Init();
  MX_TIM11_Init();
  MX_USART2_UART_Init();
  /* USER CODE BEGIN 2 */
  LoRa_init();
  gps_init();

  HAL_ADC_Start(&hadc3);

  if (BSP_LCD_Init() != LCD_OK) {
  	Error_Handler(); // Inicializace LCD selhala
  	return 1;
  }

  ssd1306_Init(); // Inicializace OLED displeje

  /* Inicializace BME280 */
  if (BME280_Config(OSRS_16, OSRS_16, OSRS_16, MODE_NORMAL, T_SB_1000, IIR_16) != 0) {
	  Error_Handler();
  }

  /* Debug pozice výběru */
  char pozice_vyberu_text[] = {
	0x50, 0x6F, 0x7A, 0x69, 0x63, 0x65, 0x20, 0x76, 0xFD, 0x62, 0xEC, 0x72, 0x75, 0x3A, 0x00,  // "Pozice výběru:"
  };

  ssd1306_SetCursor(0, 0);
  ssd1306_WriteString(pozice_vyberu_text, &Terminus12Normal, 1);

  ssd1306_SetCursor(122, 0);
  ssd1306_WriteString("0", &Terminus12Bold, 1); // Počáteční pozice výběru je vždy 0

  /* Debug stisknuto */
  char stisknuto_text[] = {
    0x53, 0x74, 0x69, 0x73, 0x6B, 0x6E, 0x75, 0x74, 0x6F, 0x3A, 0x00,  // "Stisknuto:"
  };

  ssd1306_SetCursor(0, 13);
  ssd1306_WriteString(stisknuto_text, &Terminus12Normal, 1);

  ssd1306_SetCursor(122, 13);
  ssd1306_WriteString("0", &Terminus12Bold, 1);

  ssd1306_UpdateScreen(); // Vykreslí na OLED displej

  vykresliHlavniMenu(pripojeno, ping, cas, &predchozi_pozice_vyberu, &pozice_vyberu, &max_pozice_vyberu);

  stavSD();

  HAL_TIM_Base_Start_IT(&htim11); // Inicializace timeru pro přerušení každou sekundu
  HAL_TIM_Encoder_Start(&htim3, TIM_CHANNEL_ALL); // Inicializace timeru k rotačnímu enkodéru
  TIM3->CNT = 0; // Počáteční vynulování
  /* USER CODE END 2 */

  /* Infinite loop */
  /* USER CODE BEGIN WHILE */
  while (1)
  {

	  if (mereni) {
		  BME280_Measure(&teplota, &vlhkost, &tlak);
		  pripravitDataProOdeslani();
		  mereni = false;
	  }

	  LoRa_loop();
	  gps_loop();

	  aktualizujPoziciVyberu();
	  if (stisknuto == 1) {
		  stisknuto = 0;
		  tlacitkoStisknuto();
	  }

	  stavSD();
	  if (je_cas_zapsat_log) {
		  char teplota_hodnota_text[20];
		  char vlhkost_hodnota_text[20];
		  char tlak_hodnota_text[20];

		  char teplota_venku_hodnota_text[20];
		  char vlhkost_venku_hodnota_text[20];
		  char tlak_venku_hodnota_text[20];

		  konverzeNamerenychHodnotSigned(teplota, 100, 2, teplota_hodnota_text, sizeof(teplota_hodnota_text));
		  konverzeNamerenychHodnotUnsigned(vlhkost, 1024, 3, vlhkost_hodnota_text, sizeof(vlhkost_hodnota_text));
		  konverzeNamerenychHodnotUnsigned(tlak, 256, 1, tlak_hodnota_text, sizeof(tlak_hodnota_text));

		  konverzeNamerenychHodnotSigned(teplota_venku, 100, 2, teplota_venku_hodnota_text, sizeof(teplota_venku_hodnota_text));
		  konverzeNamerenychHodnotUnsigned(vlhkost_venku, 1024, 3, vlhkost_venku_hodnota_text, sizeof(vlhkost_venku_hodnota_text));
		  konverzeNamerenychHodnotUnsigned(tlak_venku, 256, 1, tlak_venku_hodnota_text, sizeof(tlak_venku_hodnota_text));

		  char log[170];
	  	  snprintf(log, 170, "%02d.%02d.%04d;%02d:%02d:%02d;%s;%s;%s;%s;%s;%s\n", cas.den, cas.mesic, cas.rok, cas.hodiny, cas.minuty, cas.sekundy, teplota_hodnota_text, vlhkost_hodnota_text, tlak_hodnota_text, teplota_venku_hodnota_text, vlhkost_venku_hodnota_text, tlak_venku_hodnota_text);
	  	  zapsatLog("atm.csv", log);

	  	  je_cas_zapsat_log = false;
	  }

	  if (strana == 0) { // Hlavní menu
		  aktualizujHodinyVHlavnimMenu(cas, &predchozi_cas);
		  aktualizujStavSDKartyVHlavnimMenu(sd_karta_pripojena, kapacita_sd_karty, zaplneni_sd_karty);
	  }
	  if (strana == 1) { // Atmosféra
		  aktualizujHodnotyNaStranceAtmosfera(teplota, vlhkost, tlak, teplota_venku, vlhkost_venku, tlak_venku);
	  }
    /* USER CODE END WHILE */

    /* USER CODE BEGIN 3 */
  }
  /* USER CODE END 3 */
}

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
/* USER CODE BEGIN 4 */
void HAL_GPIO_EXTI_Callback(uint16_t GPIO_Pin) {
	if (GPIO_Pin == ENC_SW_Pin) {
		stisknuto = 1;
	}
	if (GPIO_Pin == LoRa_DIO1_Pin) {
		LoRa_DIO1_interrupt_handler();
	}
}

void HAL_TIM_PeriodElapsedCallback(TIM_HandleTypeDef *htim) {
	if (htim->Instance == TIM2) {
		LoRa_TIM2_interrupt_handler();
	}

    if (htim->Instance == TIM11) {
        // Kód, který se spustí každou sekundu:
    	mereni = true;
    	aktualizujCas(&cas);
    	if (cas.sekundy == 0) {
    		je_cas_zapsat_log = true;
    	}
    }
}

void HAL_UART_RxCpltCallback(UART_HandleTypeDef *huart) {
	if (huart->Instance == USART2) {
		gps_UART_RxCpltCallback_handler();
	}
}
/* USER CODE END 4 */

 /* MPU Configuration */

void MPU_Config(void)
{
  MPU_Region_InitTypeDef MPU_InitStruct = {0};

  /* Disables the MPU */
  HAL_MPU_Disable();

  /** Initializes and configures the Region and the memory to be protected
  */
  MPU_InitStruct.Enable = MPU_REGION_ENABLE;
  MPU_InitStruct.Number = MPU_REGION_NUMBER0;
  MPU_InitStruct.BaseAddress = 0x0;
  MPU_InitStruct.Size = MPU_REGION_SIZE_4GB;
  MPU_InitStruct.SubRegionDisable = 0x87;
  MPU_InitStruct.TypeExtField = MPU_TEX_LEVEL0;
  MPU_InitStruct.AccessPermission = MPU_REGION_NO_ACCESS;
  MPU_InitStruct.DisableExec = MPU_INSTRUCTION_ACCESS_DISABLE;
  MPU_InitStruct.IsShareable = MPU_ACCESS_SHAREABLE;
  MPU_InitStruct.IsCacheable = MPU_ACCESS_NOT_CACHEABLE;
  MPU_InitStruct.IsBufferable = MPU_ACCESS_NOT_BUFFERABLE;

  HAL_MPU_ConfigRegion(&MPU_InitStruct);
  /* Enables the MPU */
  HAL_MPU_Enable(MPU_PRIVILEGED_DEFAULT);

}

/**
  * @brief  This function is executed in case of error occurrence.
  * @retval None
  */
void Error_Handler(void)
{
  /* USER CODE BEGIN Error_Handler_Debug */
  /* User can add his own implementation to report the HAL error return state */
  __disable_irq();
  while (1)
  {
  }
  /* USER CODE END Error_Handler_Debug */
}
#ifdef USE_FULL_ASSERT
/**
  * @brief  Reports the name of the source file and the source line number
  *         where the assert_param error has occurred.
  * @param  file: pointer to the source file name
  * @param  line: assert_param error line source number
  * @retval None
  */
void assert_failed(uint8_t *file, uint32_t line)
{
  /* USER CODE BEGIN 6 */
  /* User can add his own implementation to report the file name and line number,
     ex: printf("Wrong parameters value: file %s on line %d\r\n", file, line) */
  /* USER CODE END 6 */
}
#endif /* USE_FULL_ASSERT */

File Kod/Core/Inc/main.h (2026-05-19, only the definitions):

#define SIRKA_DISPLEJE							320
#define VYSKA_DISPLEJE							480
#define BARVA_POZADI 							RGB888TORGB565(0, 0, 0)
#define BARVA_UI_PRIMARNI 						RGB888TORGB565(18, 255, 3)
#define BARVA_UI_SEKUNDARNI 					RGB888TORGB565(255, 255, 255)
#define BARVA_UI_TERCIARNI 						RGB888TORGB565(112, 112, 112)
#define BARVA_VYBER 							RGB888TORGB565(255, 0, 255)
#define BARVA_UPOZORNENI 						RGB888TORGB565(253, 25, 2)
#define BARVA_PINU_SD_KARTY 					RGB888TORGB565(200, 166, 32)
#define PADDING									2
#define MEZERA									20 // Širší mezera mezi UI elementy
#define BORDER									1 // Pozn.: Slouží pouze pro výpočty, vykreslování širších borderů není implementováno
#define SD_CS_Pin GPIO_PIN_4
#define SD_CS_GPIO_Port GPIOE
#define LCD_RS_Pin GPIO_PIN_0
#define LCD_RS_GPIO_Port GPIOF
#define ENC_SW_Pin GPIO_PIN_5
#define ENC_SW_GPIO_Port GPIOC
#define ENC_SW_EXTI_IRQn EXTI9_5_IRQn
#define LoRa_BUSY_Pin GPIO_PIN_1
#define LoRa_BUSY_GPIO_Port GPIOB
#define LCD_D4_Pin GPIO_PIN_7
#define LCD_D4_GPIO_Port GPIOE
#define LCD_D5_Pin GPIO_PIN_8
#define LCD_D5_GPIO_Port GPIOE
#define LCD_D6_Pin GPIO_PIN_9
#define LCD_D6_GPIO_Port GPIOE
#define LCD_D7_Pin GPIO_PIN_10
#define LCD_D7_GPIO_Port GPIOE
#define LoRa_RESET_Pin GPIO_PIN_12
#define LoRa_RESET_GPIO_Port GPIOE
#define LoRa_DIO1_Pin GPIO_PIN_15
#define LoRa_DIO1_GPIO_Port GPIOE
#define LoRa_DIO1_EXTI_IRQn EXTI15_10_IRQn
#define SPI2_NSS_Pin GPIO_PIN_12
#define SPI2_NSS_GPIO_Port GPIOB
#define LED_Pin GPIO_PIN_15
#define LED_GPIO_Port GPIOB
#define BME280_MODE_SELECT_Pin GPIO_PIN_10
#define BME280_MODE_SELECT_GPIO_Port GPIOD
#define LCD_D0_Pin GPIO_PIN_14
#define LCD_D0_GPIO_Port GPIOD
#define LCD_D1_Pin GPIO_PIN_15
#define LCD_D1_GPIO_Port GPIOD
#define SPI3_A0_Pin GPIO_PIN_2
#define SPI3_A0_GPIO_Port GPIOG
#define SPI3_A1_Pin GPIO_PIN_3
#define SPI3_A1_GPIO_Port GPIOG
#define SPI3_A2_Pin GPIO_PIN_4
#define SPI3_A2_GPIO_Port GPIOG
#define SPI3_NSS_Pin GPIO_PIN_15
#define SPI3_NSS_GPIO_Port GPIOA
#define LCD_D2_Pin GPIO_PIN_0
#define LCD_D2_GPIO_Port GPIOD
#define LCD_D3_Pin GPIO_PIN_1
#define LCD_D3_GPIO_Port GPIOD
#define LCD_RD_Pin GPIO_PIN_4
#define LCD_RD_GPIO_Port GPIOD
#define LCD_WR_Pin GPIO_PIN_5
#define LCD_WR_GPIO_Port GPIOD
#define LCD_CS_Pin GPIO_PIN_7
#define LCD_CS_GPIO_Port GPIOD
#define LCD_Reset_Pin GPIO_PIN_9
#define LCD_Reset_GPIO_Port GPIOG
#define GPS_UART_HANDLE huart2
#define LORA_SPI_HANDLE hspi2
#define BME280_SPI_HANDLE hspi3
#define SD_SPI_HANDLE hspi4

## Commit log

2026-05-18 Konfigurace GPS v STM32CubeMX
2026-05-19 Čekání na inicializaci periferií při power-up
2026-05-19 Timery se spouští až po inicializaci periferií
2026-05-20 Add 3D models
    [Monitor unit PCB holder.stl, Monitor unit roof.stl, Supervisor unit PCB holder.stl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]

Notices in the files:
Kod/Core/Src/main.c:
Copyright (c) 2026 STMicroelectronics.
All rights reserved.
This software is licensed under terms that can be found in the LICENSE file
